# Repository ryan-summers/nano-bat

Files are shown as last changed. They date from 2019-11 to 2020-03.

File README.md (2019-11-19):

# NanoBat

This repository contains the hardware and software behind NanoBat, a low-cost tool designed for
engineers and hobbyists to simulate batteries in low-power designs.

## Goals
Develop an open-source PCB design and firmware solution for simulating batteries for low-power
designs with a final cost of less than $100 per unit and can accurately simulate battery capacity
over a 24 hour window with **TBD** accuracy.

## Tools
The firmware will be developed in Rust.

The PCB design will be conducted with Kicad.

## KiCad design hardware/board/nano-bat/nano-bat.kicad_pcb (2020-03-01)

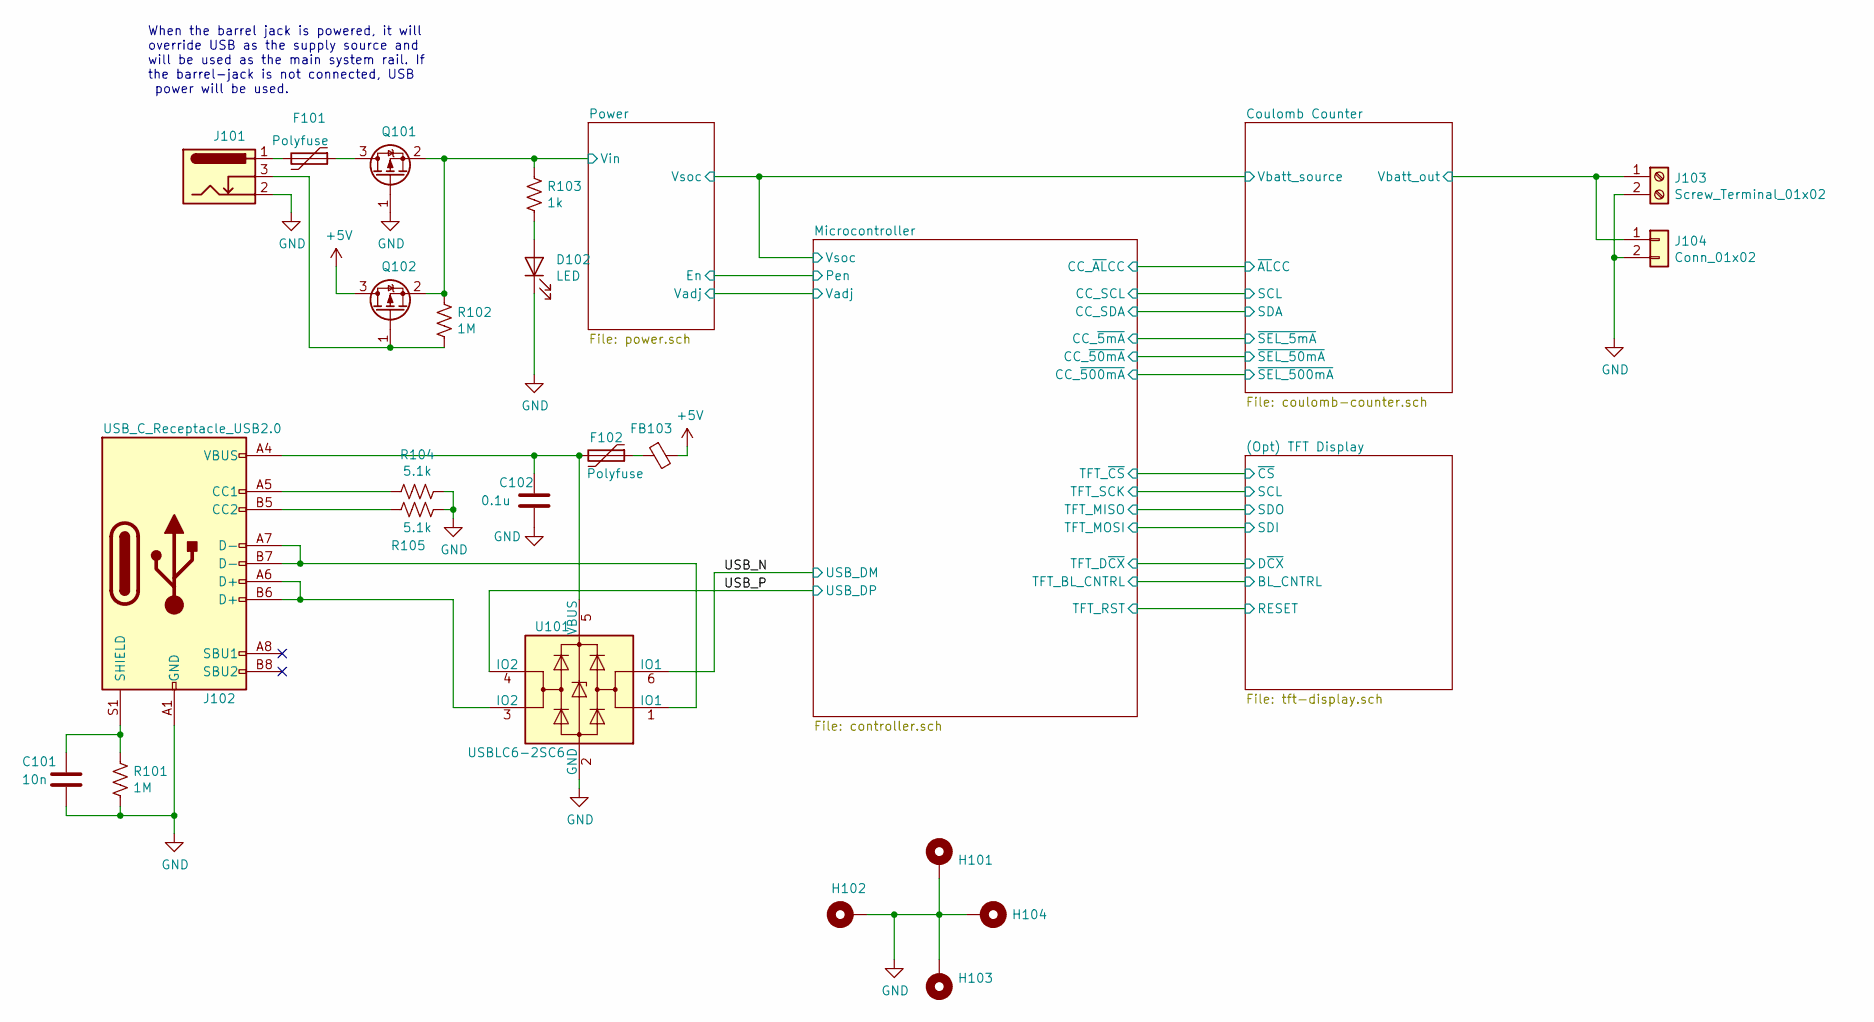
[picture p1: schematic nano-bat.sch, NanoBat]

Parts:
C101: 10n; C_0603_1608Metric; Part 399-7842-1-ND
C102: 0.1u; C_0603_1608Metric; Part 1276-1258-1-ND
D102: LED; LED_0805_2012Metric; Part 160-1423-1-ND
F101, F102: Polyfuse; Fuse_1812_4532Metric; Part 507-1763-1-ND
FB103: Ferrite_Bead_Small; R_0603_1608Metric; Part 587-1923-1-ND
H101, H102, H103, H104: e; MountingHole_2.2mm_M2_Pad
J101: Barrel_Jack_Switch; CUI_PJ-202B; Part CP-202B-ND
J102: USB_C_Receptacle_USB2.0; USB_C_Receptacle_GCT_USB4085; Part 2073-USB4085-GF-ACT-ND
J103: Screw_Terminal_01x02; TerminalBlock_Phoenix_PT-1,5-2-3.5-H_1x02_P3.50mm_Horizontal; Part 277-1721-ND
J104: Conn_01x02; JST_PH_S2B-PH-SM4-TB_1x02-1MP_P2.00mm_Horizontal; Part 455-1749-1-ND
Q101, Q102: Q_PMOS_GSD; SOT-23; Part FDN352APCT-ND
R101, R102: 1M; R_0603_1608Metric; Part 311-1.00MHRCT-ND
R103: 1k; R_0603_1608Metric; Part 311-1.0KGRCT-ND
R104, R105: 5.1k; R_0603_1608Metric; Part RMCF0603JT5K10CT-ND
U101: USBLC6-2SC6; SOT-23-6; Part 497-5235-1-ND

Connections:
+5V: FB103.2, Q102.3 (D)
/Coulomb Counter/Vbatt_out: J103.1, J104.1; also elsewhere on the board
/Power/Vin: Q101.2 (S), Q102.2 (S), R102.1, R103.1; also elsewhere on the board
/USB_N: U101.6 (IO1); also elsewhere on the board
/USB_P: U101.4 (IO2); also elsewhere on the board
GND: C101.2, C102.2, D102.1 (K), H101.1, H102.1, H103.1, H104.1, J101.2, J102.A1 (GND), J102.A12 (GND), J102.B1 (GND), J102.B12 (GND), J103.2, J104.2, Q101.1 (G), R101.2, R104.2, R105.2, U101.2 (GND); also elsewhere on the board
unnamed: C101.1, J102.S1 (SHIELD), R101.1
unnamed: C102.1, F102.2, J102.A4 (VBUS), J102.A9 (VBUS), J102.B4 (VBUS), J102.B9 (VBUS), U101.5 (VBUS)
unnamed: D102.2 (A), R103.2
unnamed: F101.1, Q101.3 (D)
unnamed: F101.2, J101.1
unnamed: F102.1, FB103.1
unnamed: J101.3, Q102.1 (G), R102.2
unnamed: J102.A5 (CC1), R104.1
unnamed: J102.A6 (D+), J102.B6 (D+), U101.3 (IO2)
unnamed: J102.A7 (D-), J102.B7 (D-), U101.1 (IO1)
unnamed: J102.B5 (CC2), R105.1

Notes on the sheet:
When the barrel jack is powered, it will override USB as the supply source and will be used as the main system rail. If the barrel-jack is not connected, USB power will be used.

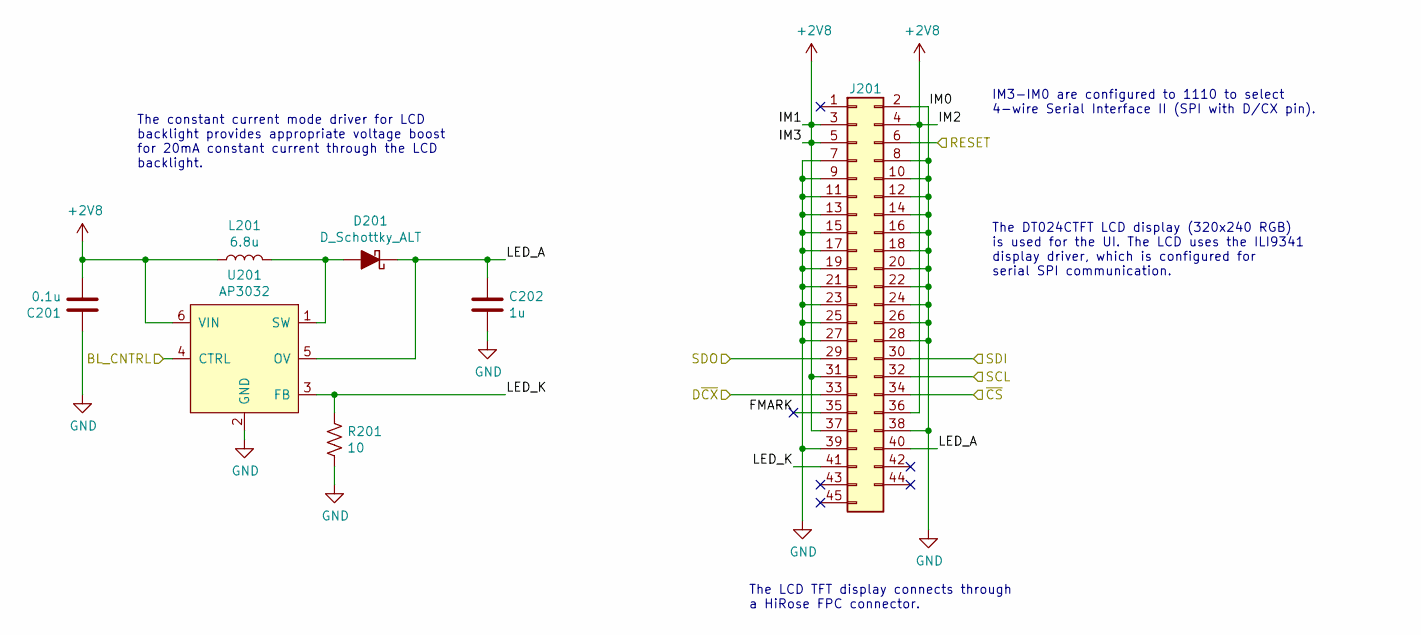
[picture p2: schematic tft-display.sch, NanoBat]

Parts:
C201: 0.1u; C_0603_1608Metric; Part 1276-1258-1-ND
C202: 1u; C_0603_1608Metric; Part 1276-1182-1-ND
D201: D_Schottky_ALT; D_SOD-323; Part BAT54HT1GOSCT-ND
J201: Conn_2Rows-45Pins; Hirose_FH12-45S-0.5SH_1x45-1MP_P0.50mm_Horizontal; Part HFA145CT-ND
L201: 6.8u; L_0805_2012Metric; Part 445-6761-1-ND
R201: 10; R_0603_1608Metric; Part 311-10.0HRCT-ND
U201: AP3032; SOT-23-6; Part AP3032KTR-G1DICT-ND

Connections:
+2V8: C201.2, J201.3, J201.4, J201.5, J201.31, J201.36, J201.37, L201.1, U201.6 (VIN); also elsewhere on the board
/(Opt) TFT Display/BL_CNTRL: U201.4 (CTRL); also elsewhere on the board
/(Opt) TFT Display/D~CX: J201.33; also elsewhere on the board
/(Opt) TFT Display/FMARK: J201.35
/(Opt) TFT Display/LED_A: C202.1, D201.1 (K), J201.40, U201.5 (OV)
/(Opt) TFT Display/LED_K: J201.41, R201.1, U201.3 (FB)
/(Opt) TFT Display/RESET: J201.6; also elsewhere on the board
/(Opt) TFT Display/SCL: J201.32; also elsewhere on the board
/(Opt) TFT Display/SDI: J201.30; also elsewhere on the board
/(Opt) TFT Display/SDO: J201.29; also elsewhere on the board
/Microcontroller/TFT_~CS: J201.34; also elsewhere on the board
GND: C201.1, C202.2, J201.2, J201.7, J201.8, J201.9, J201.10, J201.11, J201.12, J201.13, J201.14, J201.15, J201.16, J201.17, J201.18, J201.19, J201.20, J201.21, J201.22, J201.23, J201.24, J201.25, J201.26, J201.27, J201.28, J201.38, J201.39, R201.2, U201.2 (GND); also elsewhere on the board
unnamed: D201.2 (A), L201.2, U201.1 (SW)

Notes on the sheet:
The constant current mode driver for LCD backlight provides appropriate voltage boost for 20mA constant current through the LCD backlight.
The LCD TFT display connects through a HiRose FPC connector.
The DT024CTFT LCD display (320x240 RGB) is used for the UI. The LCD uses the ILI9341 display driver, which is configured for serial SPI communication.
IM3-IM0 are configured to 1110 to select 4-wire Serial Interface II (SPI with D/CX pin).

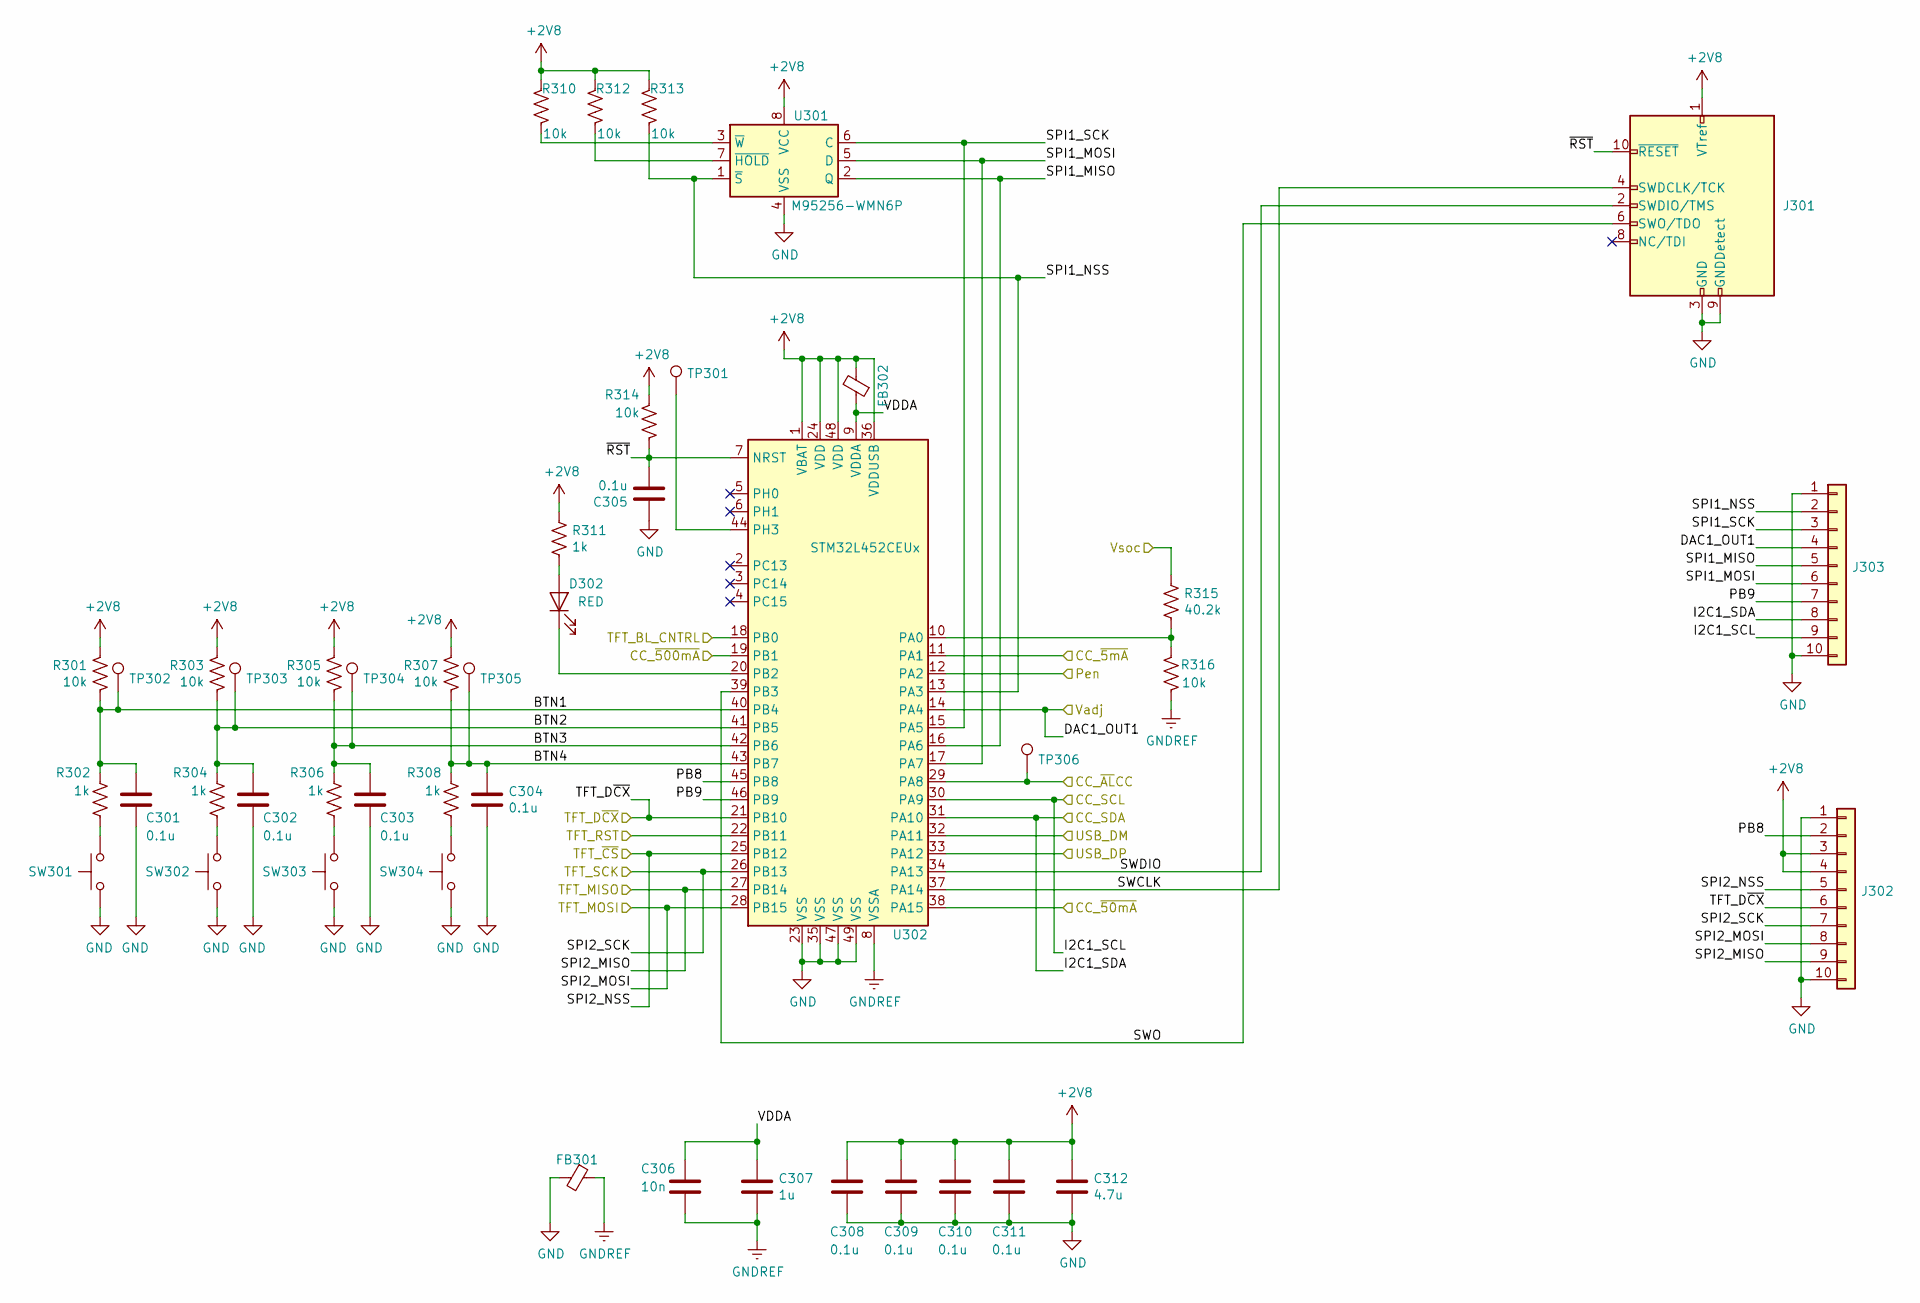
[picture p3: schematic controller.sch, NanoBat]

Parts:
C301, C302, C303, C304, C305, C308, C309, C310, C311: 0.1u; C_0603_1608Metric; Part 1276-1258-1-ND
C306: 10n; C_0603_1608Metric; Part 399-7842-1-ND
C307: 1u; C_0603_1608Metric; Part 1276-1182-1-ND
C312: 4.7u; C_0603_1608Metric; Part 399-3482-1-ND
D302: RED; LED_0805_2012Metric; Part 475-1278-1-ND
FB301, FB302: Ferrite_Bead_Small; R_0603_1608Metric; Part 587-1923-1-ND
J301: Conn_ARM_JTAG_SWD_10; PinHeader_2x05_P1.27mm_Vertical_SMD; Part SAM8796-ND
J302, J303: Conn_01x10; PinHeader_1x10_P2.54mm_Vertical; Part 609-3301-ND
R301, R303, R305, R307, R310, R312, R313, R314, R316: 10k; R_0603_1608Metric; Part 311-10KGRCT-ND
R302, R304, R306, R308, R311: 1k; R_0603_1608Metric; Part 311-1.0KGRCT-ND
R315: 40.2k; R_0603_1608Metric; Part RR08P40.2KDCT-ND
SW301, SW302, SW303, SW304: SW_Push; SW_B3FS-1010P; Part SW1440CT-ND
TP301: TestPoint; TestPoint_THTPad_D1.0mm_Drill0.5mm
TP302, TP303, TP304, TP305, TP306: TestPoint; TestPoint_Pad_D1.0mm
U301: M95256-WMN6P; SOIC-8_3.9x4.9mm_P1.27mm; Part 497-6357-5-ND
U302: STM32L452CEUx; QFN-48-1EP_7x7mm_P0.5mm_EP5.6x5.6mm; Part 497-17218-ND

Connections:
+2V8: C308.1, C309.1, C310.1, C311.1, C312.1, FB302.2, J301.1 (VTref), J302.3, J302.4, R301.1, R303.1, R305.1, R307.1, R310.1, R311.1, R312.1, R313.1, R314.1, U301.8 (VCC), U302.1 (VBAT), U302.24 (VDD), U302.36 (VDDUSB), U302.48 (VDD); also elsewhere on the board
/(Opt) TFT Display/BL_CNTRL: U302.18 (PB0); also elsewhere on the board
/(Opt) TFT Display/D~CX: J302.6, U302.21 (PB10); also elsewhere on the board
/(Opt) TFT Display/RESET: U302.22 (PB11); also elsewhere on the board
/(Opt) TFT Display/SCL: J302.7, U302.26 (PB13); also elsewhere on the board
/(Opt) TFT Display/SDI: J302.8, U302.28 (PB15); also elsewhere on the board
/(Opt) TFT Display/SDO: J302.9, U302.27 (PB14); also elsewhere on the board
/Coulomb Counter/Vbatt_source: R315.1; also elsewhere on the board
/Microcontroller/BTN1: C301.1, R301.2, R302.1, TP302.1, U302.40 (PB4)
/Microcontroller/BTN2: C302.1, R303.2, R304.1, TP303.1, U302.41 (PB5)
/Microcontroller/BTN3: C303.1, R305.2, R306.1, TP304.1, U302.42 (PB6)
/Microcontroller/BTN4: C304.1, R307.2, R308.1, TP305.1, U302.43 (PB7)
/Microcontroller/CC_SCL: J303.9, U302.30 (PA9); also elsewhere on the board
/Microcontroller/CC_SDA: J303.8, U302.31 (PA10); also elsewhere on the board
/Microcontroller/CC_~5mA: U302.11 (PA1); also elsewhere on the board
/Microcontroller/CC_~50mA: U302.38 (PA15); also elsewhere on the board
/Microcontroller/CC_~500mA: U302.19 (PB1); also elsewhere on the board
/Microcontroller/CC_~AL~CC: TP306.1, U302.29 (PA8); also elsewhere on the board
/Microcontroller/PB8: J302.2, U302.45 (PB8)
/Microcontroller/PB9: J303.7, U302.46 (PB9)
/Microcontroller/SPI1_MISO: J303.5, U301.2 (Q), U302.16 (PA6)
/Microcontroller/SPI1_MOSI: J303.6, U301.5 (D), U302.17 (PA7)
/Microcontroller/SPI1_NSS: J303.2, R313.2, U301.1 (~S), U302.13 (PA3)
/Microcontroller/SPI1_SCK: J303.3, U301.6 (C), U302.15 (PA5)
/Microcontroller/SWCLK: J301.4 (SWDCLK/TCK), U302.37 (PA14)
/Microcontroller/SWDIO: J301.2 (SWDIO/TMS), U302.34 (PA13)
/Microcontroller/SWO: J301.6 (SWO/TDO), U302.39 (PB3)
/Microcontroller/TFT_~CS: J302.5, U302.25 (PB12); also elsewhere on the board
/Microcontroller/VDDA: C306.1, C307.1, FB302.1, U302.9 (VDDA)
/Microcontroller/Vadj: J303.4, U302.14 (PA4); also elsewhere on the board
/Microcontroller/~RST: C305.2, J301.10 (~RESET~), R314.2, U302.7 (NRST)
/Power/En: U302.12 (PA2); also elsewhere on the board
/USB_N: U302.32 (PA11); also elsewhere on the board
/USB_P: U302.33 (PA12); also elsewhere on the board
GND: C301.2, C302.2, C303.2, C304.2, C305.1, C308.2, C309.2, C310.2, C311.2, C312.2, FB301.2, J301.3 (GND), J301.5 (GND), J301.9 (GNDDetect), J302.1, J302.10, J303.1, J303.10, SW301.2, SW302.2, SW303.2, SW304.2, U301.4 (VSS), U302.23 (VSS), U302.35 (VSS), U302.47 (VSS), U302.49 (VSS); also elsewhere on the board
GNDREF: C306.2, C307.2, FB301.1, R316.2, U302.8 (VSSA)
unnamed: D302.1 (K), U302.20 (PB2)
unnamed: D302.2 (A), R311.2
unnamed: R302.2, SW301.1
unnamed: R304.2, SW302.1
unnamed: R306.2, SW303.1
unnamed: R308.2, SW304.1
unnamed: R310.2, U301.3 (~W)
unnamed: R312.2, U301.7 (~HOLD)
unnamed: R315.2, R316.1, U302.10 (PA0)
unnamed: TP301.1, U302.44 (PH3)

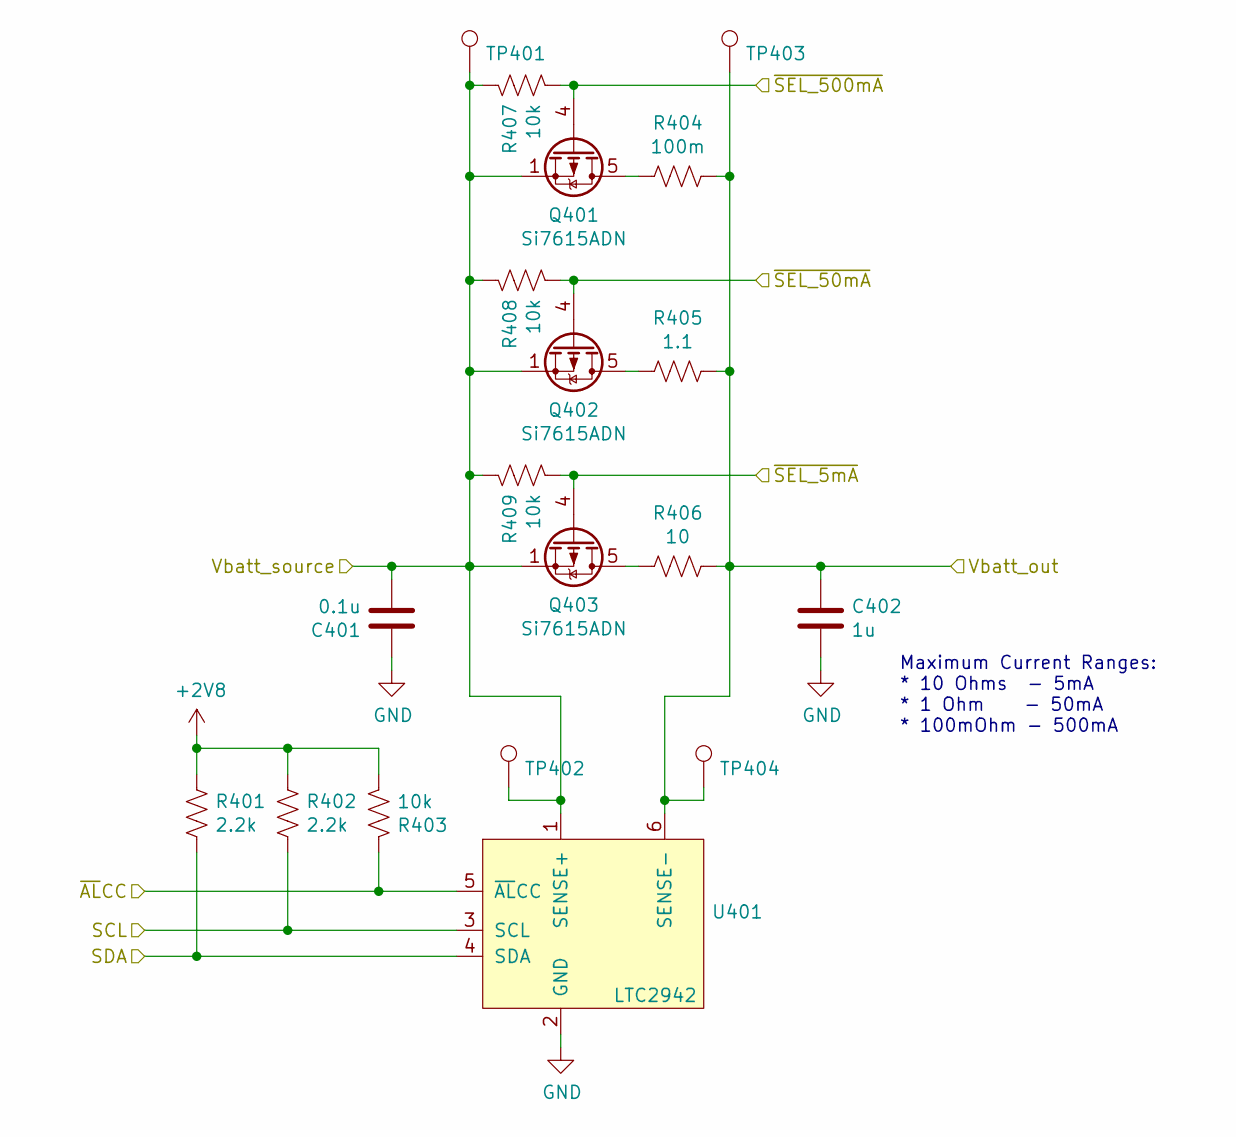
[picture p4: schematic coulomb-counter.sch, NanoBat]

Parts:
C401: 0.1u; C_0603_1608Metric; Part 1276-1258-1-ND
C402: 1u; C_0603_1608Metric; Part 1276-1182-1-ND
Q401, Q402, Q403: Si7615ADN; Vishay_PowerPAK_1212-8_Single; Part SI7615ADN-T1-GE3CT-ND
R401, R402: 2.2k; R_0603_1608Metric; Part P2.2KGCT-ND
R403, R407, R408, R409: 10k; R_0603_1608Metric; Part 311-10KGRCT-ND
R404: 100m; R_1206_3216Metric; Part CSR1206FKR100CT-ND
R405: 1.1; R_1206_3216Metric; Part RNCP1206FTD1R00CT-ND
R406: 10; SM6227; Part SM6227FT10R0
TP401, TP402, TP403, TP404: TestPoint; TestPoint_Pad_2.0x2.0mm; Part A106144CT-ND
U401: LTC2942; DFN-6-1EP_3x2mm_P0.5mm_EP1.65x1.35mm; Part LTC2942CDCB#TRMPBFCT-ND

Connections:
+2V8: R401.1, R402.1, R403.2; also elsewhere on the board
/Coulomb Counter/Vbatt_out: C402.1, R404.1, R405.1, R406.1, TP403.1, TP404.1, U401.6 (SENSE-); also elsewhere on the board
/Coulomb Counter/Vbatt_source: C401.2, Q401.1 (S), Q401.2 (S), Q401.3 (S), Q402.1 (S), Q402.2 (S), Q402.3 (S), Q403.1 (S), Q403.2 (S), Q403.3 (S), R407.1, R408.1, R409.1, TP401.1, TP402.1, U401.1 (SENSE+); also elsewhere on the board
/Microcontroller/CC_SCL: R402.2, U401.3 (SCL); also elsewhere on the board
/Microcontroller/CC_SDA: R401.2, U401.4 (SDA); also elsewhere on the board
/Microcontroller/CC_~5mA: Q403.4 (G), R409.2; also elsewhere on the board
/Microcontroller/CC_~50mA: Q402.4 (G), R408.2; also elsewhere on the board
/Microcontroller/CC_~500mA: Q401.4 (G), R407.2; also elsewhere on the board
/Microcontroller/CC_~AL~CC: R403.1, U401.5 (~AL~CC); also elsewhere on the board
GND: C401.1, C402.2, U401.2 (GND); also elsewhere on the board
unnamed: Q401.5 (D), R404.2
unnamed: Q402.5 (D), R405.2
unnamed: Q403.5 (D), R406.2

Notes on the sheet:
Maximum Current Ranges: * 10 Ohms - 5mA * 1 Ohm - 50mA * 100mOhm - 500mA

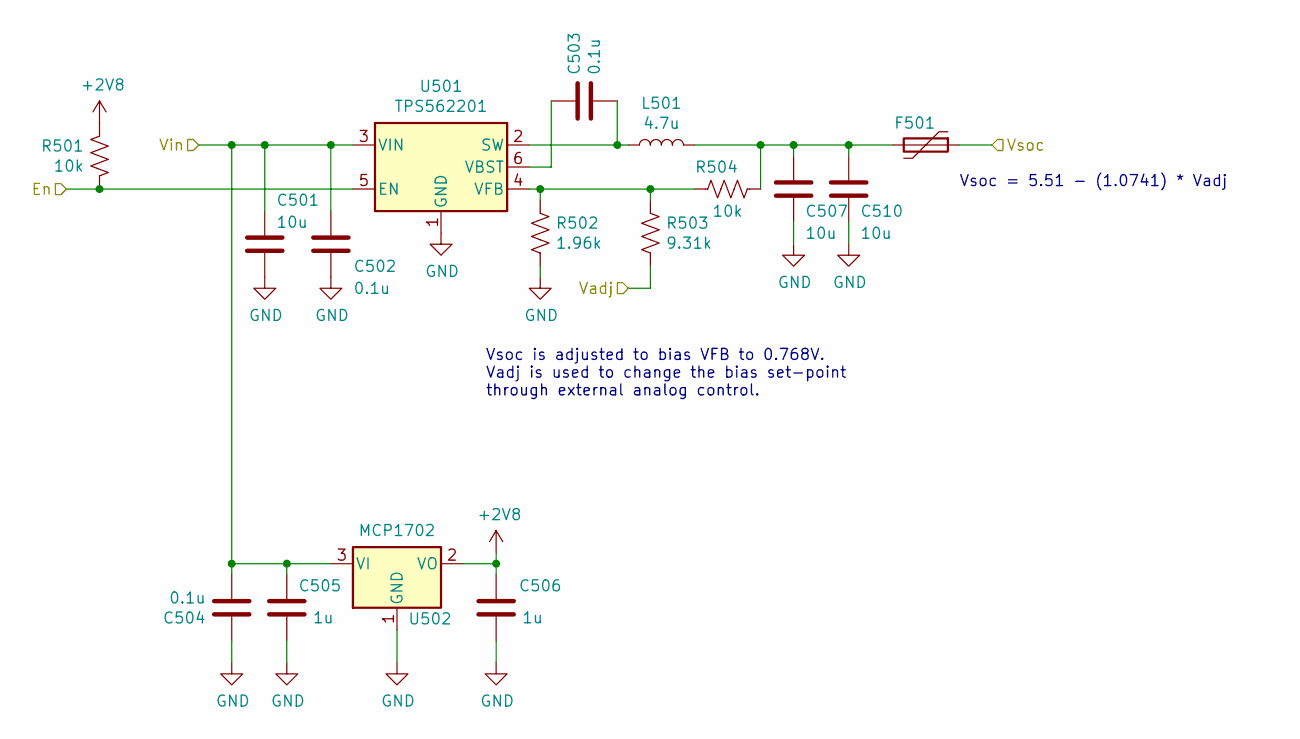
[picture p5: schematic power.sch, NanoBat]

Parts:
C501, C507, C510: 10u; C_0805_2012Metric; Part 399-3482-1-ND
C502, C503, C504: 0.1u; C_0603_1608Metric; Part 1276-1258-1-ND
C505, C506: 1u; C_0603_1608Metric; Part 1276-1182-1-ND
F501: Polyfuse; Fuse_1812_4532Metric; Part 507-1763-1-ND
L501: 4.7u; L_Taiyo-Yuden_NR-60xx; Part 587-2100-1-ND
R501: 10k; R_0603_1608Metric; Part 311-10KGRCT-ND
R502: 1.96k; R_0603_1608Metric; Part 311-1.96KHRCT-ND
R503: 9.31k; R_0603_1608Metric; Part RMCF0603FT9K31CT-ND
R504: 10k; R_0603_1608Metric; Part 311-10.0KHRCT-ND
U501: TPS562201; SOT-23-6; Part 296-44397-1-ND
U502: MCP1702; SOT-23; Part MCP1702T-3302E/CBCT-ND

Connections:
+2V8: C506.1, R501.1, U502.2 (VO); also elsewhere on the board
/Coulomb Counter/Vbatt_source: F501.1; also elsewhere on the board
/Microcontroller/Vadj: R503.2; also elsewhere on the board
/Power/En: R501.2, U501.5 (EN); also elsewhere on the board
/Power/Vin: C501.1, C502.1, C504.2, C505.1, U501.3 (VIN), U502.3 (VI); also elsewhere on the board
GND: C501.2, C502.2, C504.1, C505.2, C506.2, C507.2, C510.2, R502.2, U501.1 (GND), U502.1 (GND); also elsewhere on the board
unnamed: C503.1, U501.6 (VBST)
unnamed: C503.2, L501.1, U501.2 (SW)
unnamed: C507.1, C510.1, F501.2, L501.2, R504.2
unnamed: R502.1, R503.1, R504.1, U501.4 (VFB)

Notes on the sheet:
Vsoc is adjusted to bias VFB to 0.768V. Vadj is used to change the bias set-point through external analog control.
Vsoc = 5.51 - (1.0741) * Vadj

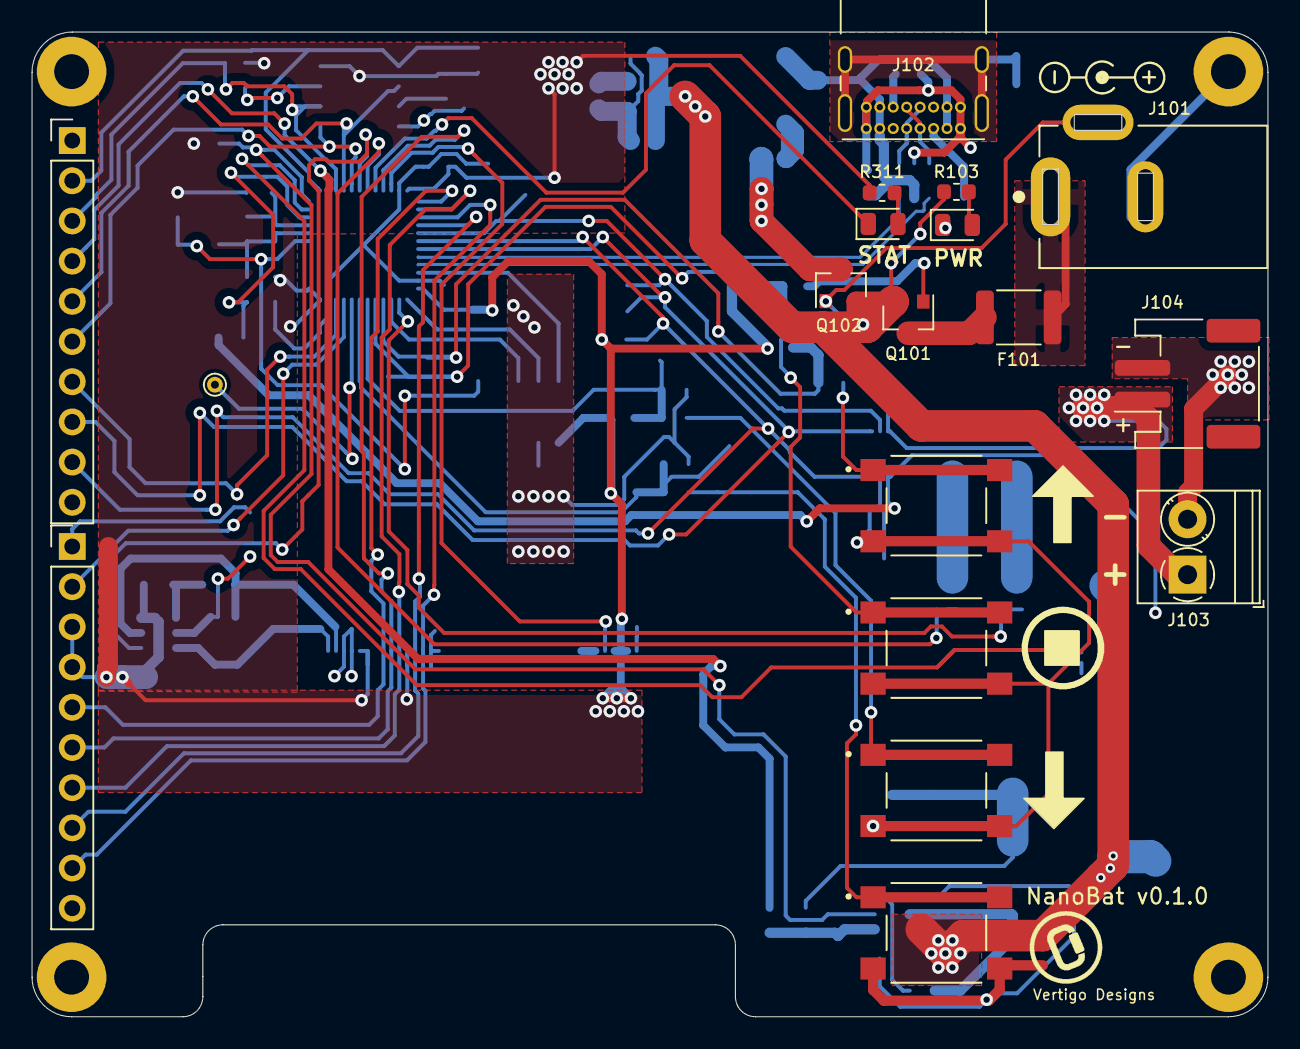
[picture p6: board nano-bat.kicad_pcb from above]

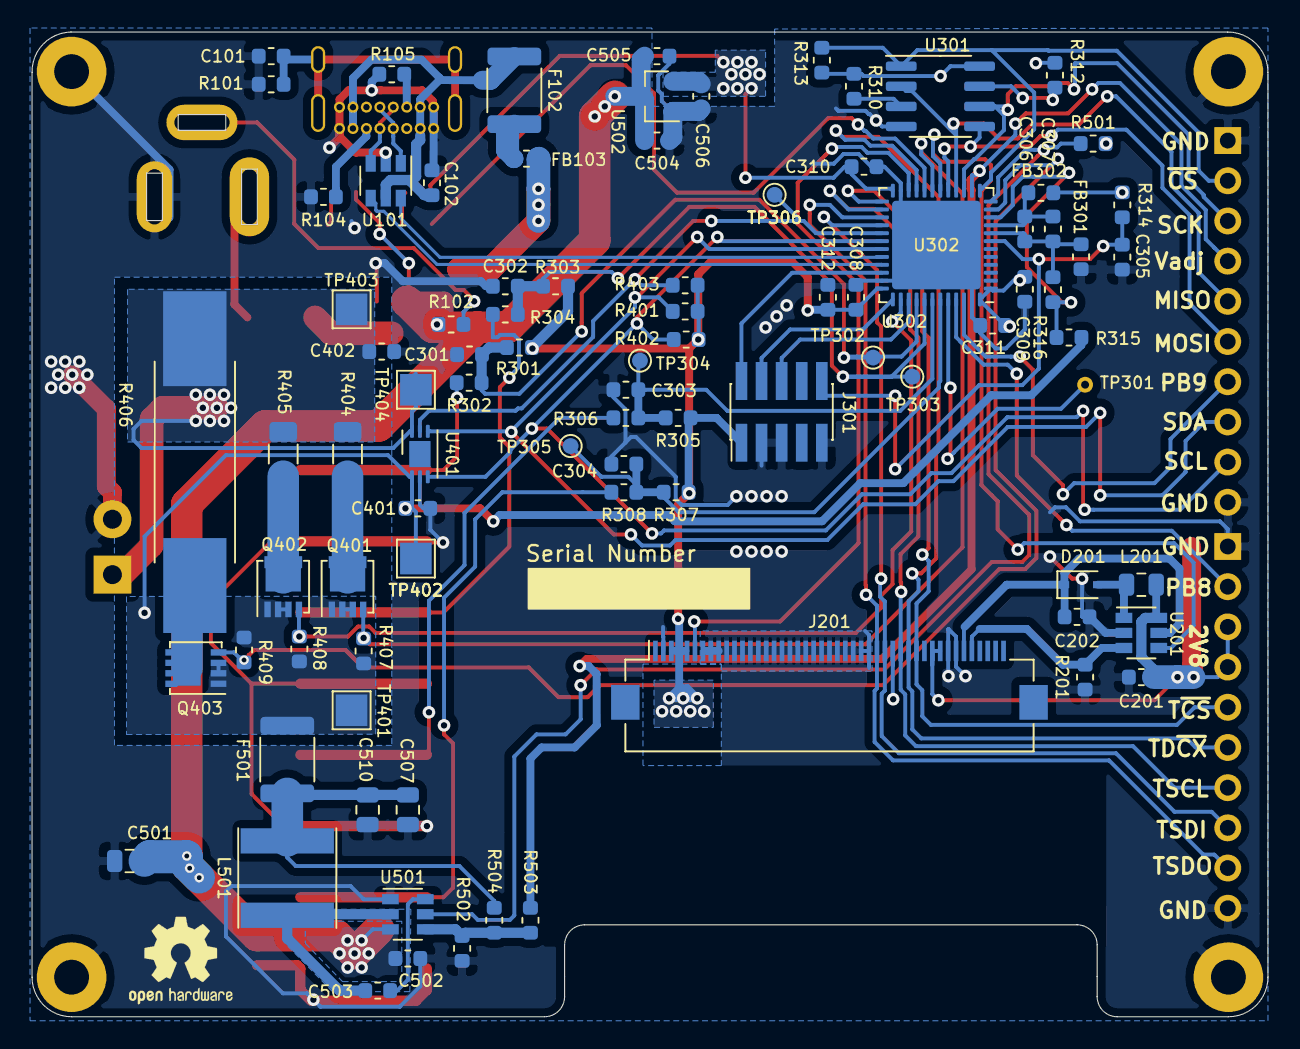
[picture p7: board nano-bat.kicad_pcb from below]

Board: 2 copper layers, 78.1 x 62.2 mm, 109 parts (87 on the bottom side), 70 nets.

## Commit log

2019-11-21 Adding initial WIP of schematic capture before upping micro size
    [controller.sch, coulomb-counter.sch, lcd-display.sch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]
2019-11-21 Adding larger microcontroller
    [controller.sch, coulomb-counter.sch, lcd-display.sch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]
2019-11-24 Adding WIP before reverting
    [controller.sch, coulomb-counter.sch, nano-bat.sch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]
2019-11-24 Adding complete schematic
    [controller.sch, lcd-display.sch, nano-bat.sch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]
2019-12-31 Adding first-pass revisions and annotations, part selection
    [controller.sch, coulomb-counter.sch, nano-bat.sch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]
2019-12-31 Adding 3D models, reorg, minor schematic fixes
    [controller.sch, nano-bat.kicad_pcb, nano-bat.sch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]
2019-12-31 Adding docs to schematic
    [controller.sch, coulomb-counter.sch, nano-bat.sch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]
2020-02-19 Adding 0.1.0 of board spin
    [controller.sch, coulomb-counter.sch, nano-bat.kicad_pcb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]
